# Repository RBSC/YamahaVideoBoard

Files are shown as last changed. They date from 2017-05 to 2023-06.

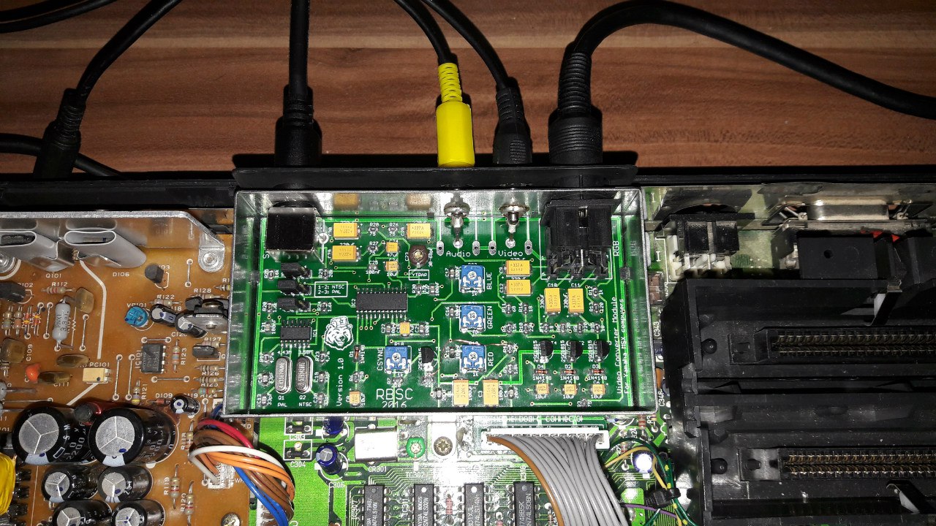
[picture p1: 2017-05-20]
Pics/installed.jpg

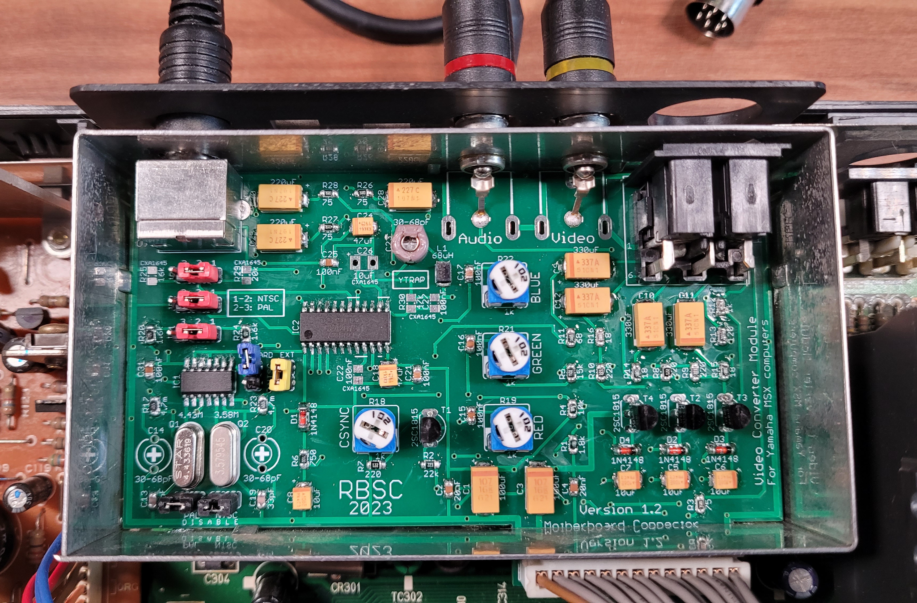
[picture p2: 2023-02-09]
Pics/tantalum_installed.jpg

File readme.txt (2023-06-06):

Improved Video Board for Yamaha MSXs version 1.2
Copyright (c) 2016-2023 RBSC

About
-----

This is the improved video board for Yamaha YIS503II, YIS503III and similar MSX/MSX2 computers to replace the original video
boards or the older versions of the video boards from RBSC. The changes to the v1.2 board comparing to the previous verions are:

- Allows to use either CXA1645 or CXA2075 video encoder chips
- Contains an improved YTRAP filter
- Allows to use through-hole electrolytic capacitors (see note below)
- Allows to switch between on-board and internal MSX's 3.58MHz clock generator for NTSC
- Allows to disable one or both on-board clock generators
- Requires less components if CXA2075 encoder is used
- If using only computer's 3.58Mhz and NTSC, there's no need to assemble both clock generators

It is possible to use some components from the old black-and-white video board from the YIS503IIIR computer to build the v1.2
board. The following components can be re-used:

- 330uF capacitors (4)
- 10uF capacitors (4)
- 2sc1684 transistors (4)
- 100uF capacitors (2)
- DIN8 female socket
- Male 13-pin connector for motherboard's cable

IMPORTANT! When installing 100uF capacitors from the original board, please make sure to install the 16v rated capacitor as C3
and the 10v rated capacitor as C2. Otherwise, the 10v rated capacitor installed as C3 may blow up!

WARNING!
--------

Do not install ONBOARD and EXT jumpers at the same time! When using the EXT jumper, disable both NTSC and PAL clock generators
with their respective jumpers (see below).

The pinout of the RGB connector on the new video board differs from the original pinout! On the new board pin 3 is connected to
+12v supply. When making RGB to SCART cables or when using such cables designed for the Japanese MSX mashines, please make sure
that you connect the +12v to the correct SCART pin - pin 8. Connecting +12v to this pin will switch the TV/monitor to 4:3 mode.

DO NOT connect the cable from Yamaha YIS805 to this video board! The pin order is different on the YIS805 and you will damage
the board if you connect it to YIS805!

It is advised to power down the computer before switching between PAL and NTSC in order to avoid damage to the encoder chip.

Settings
--------

Compared to v1.1 of the videoboard, there are more jumpers. The jumpers labeled as PAL or NTSC DISABLE are used to disable the
on-board PAL or NTSC clock generators and use the internal computer's 3.58MHz clock for NTSC encoding. The installed jumper
disables the clock generator.

The ONBOARD and EXT jumpers are used to select which clock to use for NTSC encoding. When using the EXT jumper, the computer's
internal 3.58MHz clock will be fed to the encoder chip. This will effectively eliminate all color atrefacts in the composite
video output. But this will work only with NTSC mode. The installed jumper enables either on-board or external clock signal.
Never install both jumpers at the same time! Please note that the jumper settings do not affect the RGB output.

There are three 3-pin mode selection jumpers on the video board. These jumpers are used to set the color encoding for the S-Video
and composite video outputs. All 3 jumpers must be set the same way. When the pins 1-2 of the jumpers are shorted, the NTSC
encoding is enabled. Otherwise, when pins 2-3 of the jumpers are shorted, the PAL encoding is enabled. Please note that the
jumper settings do not affect the RGB output.

When setting up the board, it's recommended to measure the voltages on the outputs of 4 potentiometers (variable resistors). The
measurement should be done on the central pin. The correct voltage setting is required to form the stable picture on the
composite video and S-Video outputs.

When using the CXA1645 encoder chip, the recommended voltage for the CSYNC variable resistor is 1.3v, the recommended voltages
for Red, Green and Blue variable resistors are from 1.5v to 2.0v, depending on the desired brightness. The voltages on R, G and
B channels must be the same to avoid color distortion. Each color should be tuned after setting it as background color - for
example when setting the blue color's voltage, use the "color15,4,4" command in Basic to set blue as background color. For
green color use the "color15,2,2" command and for red color use the "color15,6,6" command.

When using the CXA2075 encoder chip, the voltage for CSYNC variable resistor should be set to 1.5v and the voltages for Red,
Green and Blue variable resistors should be set up to 3.0v to reach the desired brightness.

Notes
-----

When using the CXA2075 video encoder, it's not neccessary to install the following elements: C22, C23, C26, C27, R25, R29, R30.
Also, if L1 is not installed, please bridge its solder pads with a wire. However, it's highly recommended to use L1 for better
results.

When planning to use only NTSC encoding with the internal MSX's clock, it may not be necessary to install both oscillators,
both trim capacitors, 74HCT04 chip, C31, C13, C19, R17, R20, R23, as well as optional capacitors on the back side of the board.

Please use the following oscillators: 3.579MHz for NTSC and 4.433MHz for PAL. Using other oscillators may cause undesired side
effects.

It is recommended to use the 74HCT04 chip for the frequency generator circuit. The HC series chips may also work, but the HCT
series is highly recommended.

There may be artefacts on the color transitions in the composite video's output when using the on-board clock generators. These
artefacts can be removed by carefully adjusting the corresponding trim capacitors (C14 or C20) with a small flat screwdriver. 

The sharpness of the composite video output can be adjusted by the C23 trim capacitor that is marked as "YTRAP". Please use a
small flat screwdriver with an isolated handle to trim the capacitors, otherwise interference will occur.

If you are using a jumper pin header instead of the original cable connector, be careful to connect the cable from the MSX's
main board correctly. Incorrect cable connection may damage the video board and your MSX computer!

IMPORTANT!
----------

The RBSC provides all the files and information for free, without any liability (see the disclaimer.txt file). The provided information,
software or hardware must not be used for commercial purposes unless permitted by the RBSC. Producing a small amount of bare boards for
personal projects and selling the rest of the batch is allowed without the permission of RBSC.

When the sources of the tools are used to create alternative projects, please always mention the original source and the copyright!

Contact information
-------------------

The members of RBSC group Tnt23, Wierzbowsky, Pyhesty, Ptero, GreyWolf, SuperMax, VWarlock and DJS3000 can be contacted via the group's
e-mail address:

info@rbsc.su

The group's coordinator could be reached via this e-mail address:

admin@rbsc.su

The group's website can be found here:

https://rbsc.su/
https://rbsc.su/ru

The RBSC's hardware repository can be found here:

https://github.com/rbsc

The RBSC's 3D model repository can be found here:

https://www.thingiverse.com/groups/rbsc/things

-= ! MSX FOREVER ! =-

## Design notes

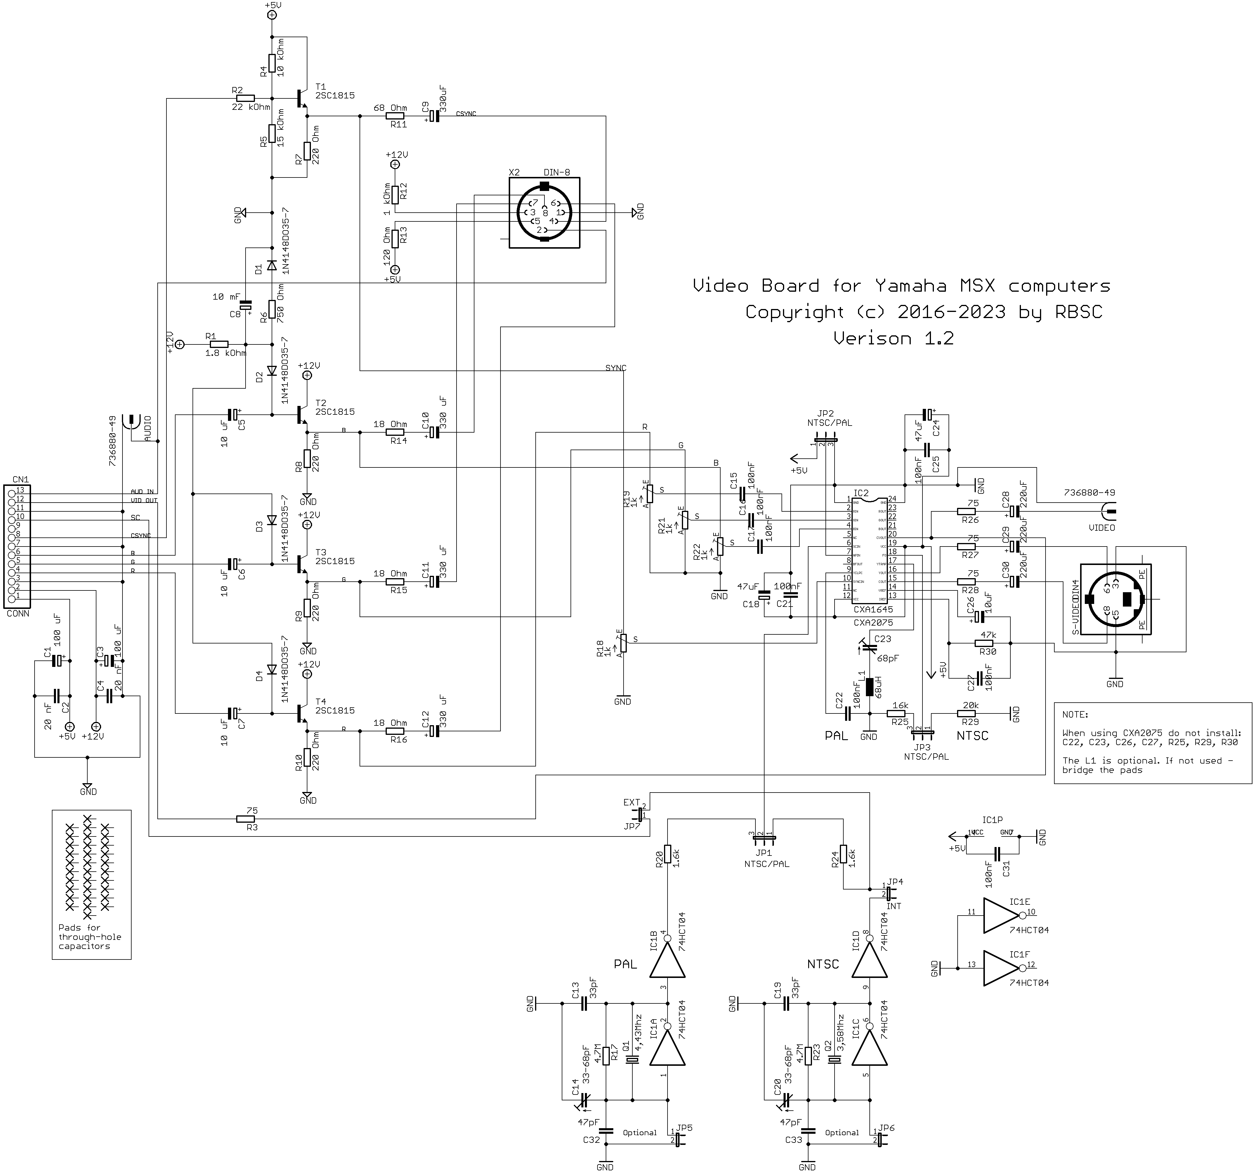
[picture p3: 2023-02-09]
Doc/schematics.png

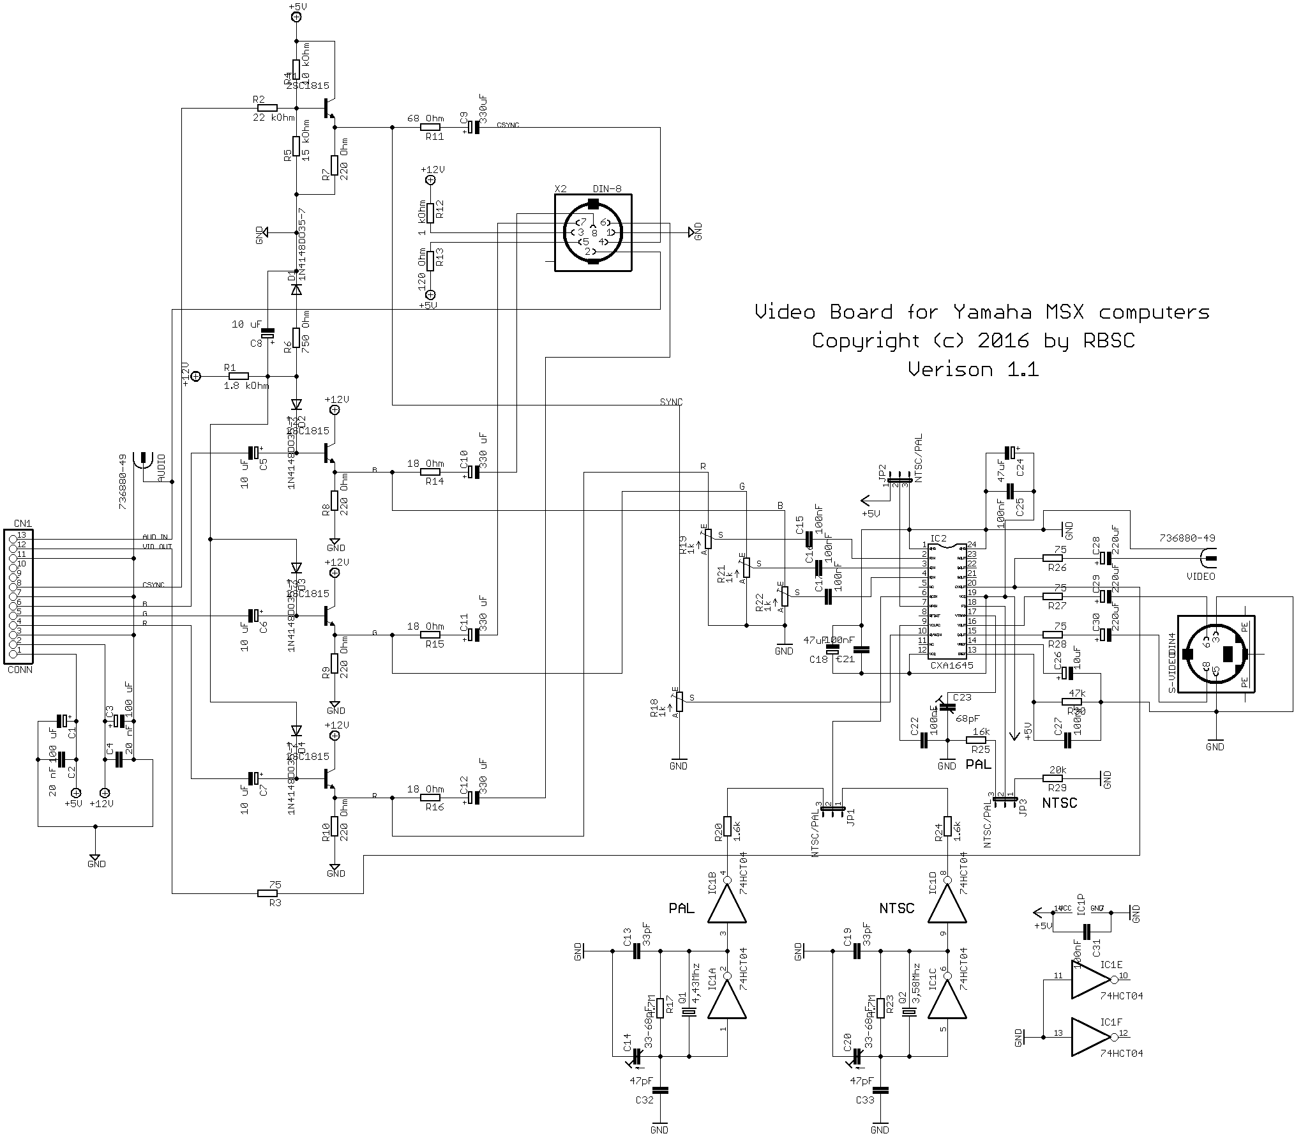
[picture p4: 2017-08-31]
Doc/schematics_v11.png

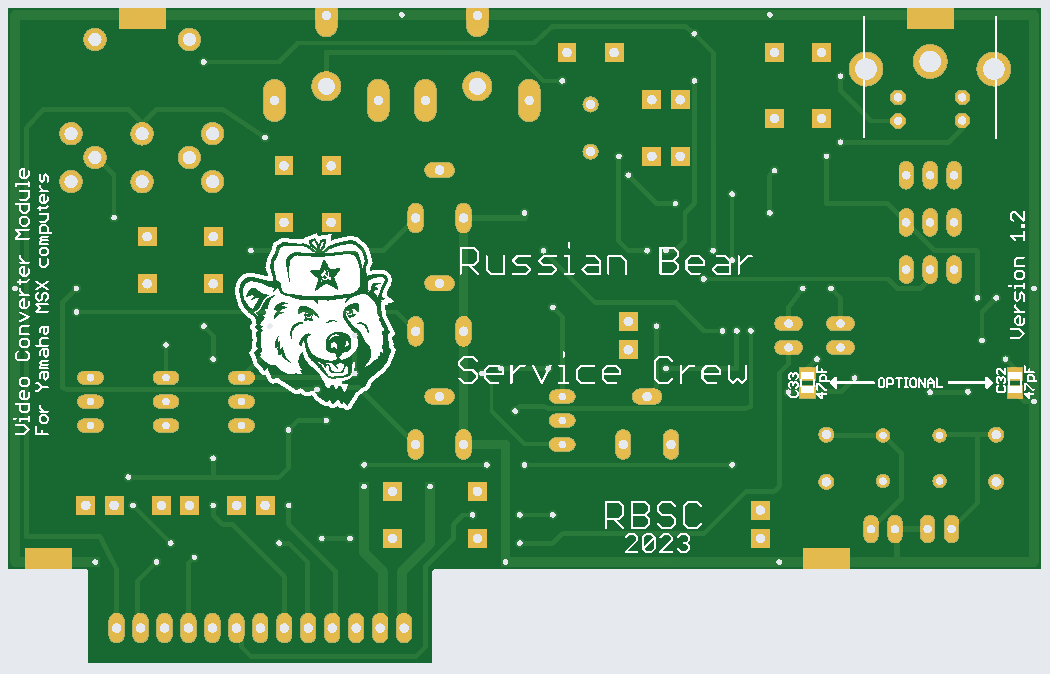
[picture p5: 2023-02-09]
Pics/board_bottom.png

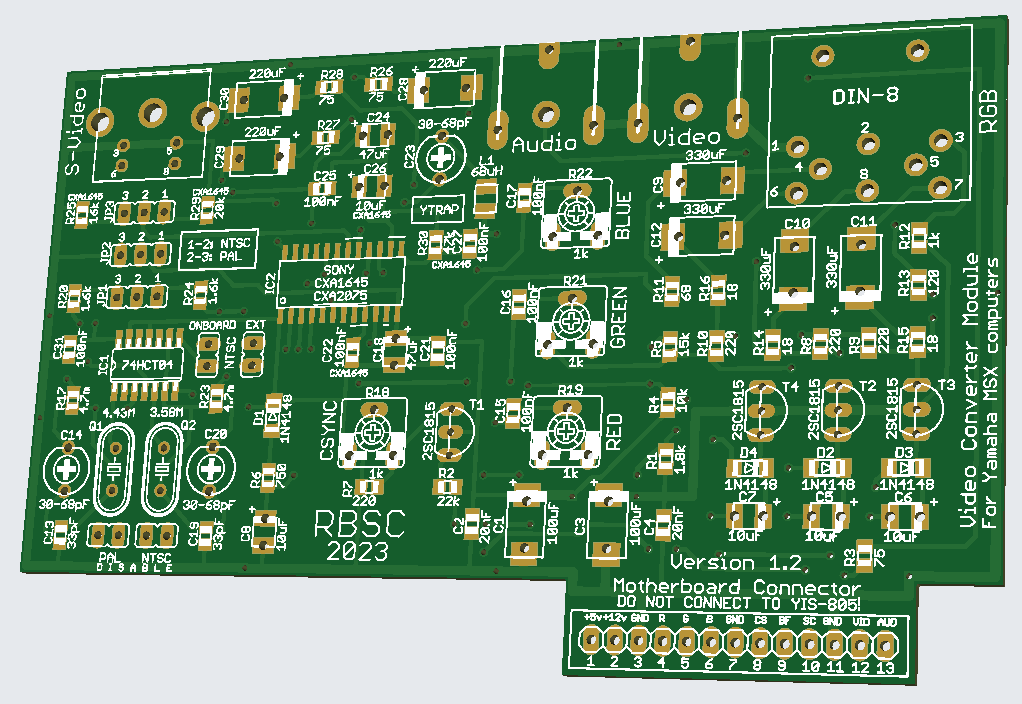
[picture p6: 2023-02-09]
Pics/board_3d.png

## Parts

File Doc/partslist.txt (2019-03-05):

Improved Video Board for Yamaha MSXs version 1.1
Copyright (c) 2016 RBSC

Partlist
--------

Assembly variant: 

Part     Value          Package   Library    Position (mm)         Orientation	Notes

AUDIO    736880-49      736880-49 con-conrad (60 65)               R270		Use Yamaha's own output (RCA)
C1       100 uF         SMC_D     rcl        (60 16)               R270		16v or more!
C2       20 nF          C0805     rcl        (54 16)               R270
C3       100 uF         SMC_D     rcl        (69 16)               R270		16v or more!
C4       20 nF          C0805     rcl        (75 16)               R270
C5       10 uF          SMC_B     rcl        (92 17)               R180		10v or more
C6       10 uF          SMC_B     rcl        (100 17)              R180		10v or more
C7       10 uF          SMC_B     rcl        (84 17)               R180		10v or more
C8       10 uF          SMC_B     rcl        (30 15)               R270		10v or more
C9       330 uF         SMC_D     rcl        (78 53)               R0		10v or more
C10      330 uF         SMC_D     rcl        (88 43)               R90		10v or more
C11      330 uF         SMC_D     rcl        (95 43)               R90		10v or more
C12      330 uF         SMC_D     rcl        (78 47)               R0		10v or more
C13      33pF           C0805     rcl        (5 14.5)              R90
C14      33-68pF        CTRIMTZ03 rcl        (5 22)                R180
C15      100nF          C0805     rcl        (58 28)               R270
C16      100nF          C0805     rcl        (58 40)               R270
C17      100nF          C0805     rcl        (58 52)               R270
C18      47uF           SMC_B     rcl        (44 35)               R270		10v or more
C19      33pF           C0805     rcl        (23 14.5)             R90
C20      33-68pF        CTRIMTZ03 rcl        (23 22)               R180
C21      100nF          C0805     rcl        (49 35)               R270
C22      100nF          C0805     rcl        (39 35)               R270
C23      68pF           CTRIMTZ03 rcl        (48 57)               R180
C24      47uF           SMC_B     rcl        (40 60)               R0		10v or more
C25      100nF          C0805     rcl        (34 54)               R0
C26      10uF           SMC_B     rcl        (40 54)               R0		10v or more
C27      100nF          C0805     rcl        (52 47)               R90
C28      220uF          SMC_D     rcl        (48 65)               R0		10v or more
C29      220uF          SMC_D     rcl        (26 58)               R180		10v or more
C30      220uF          SMC_D     rcl        (26 65)               R180		10v or more
C31      100nF          C0805     rcl        (4 36)                R90
C32      47pF           C0805     rcl        (3 30)                MR90		(optional, back side)
C33      47pF           C0805     rcl        (25 30)               MR90		(optional, back side)
CONN     CN1            1X13      pinhead    (83 4)                R0
D1       1N4148DO35-7   MINIMELF  diode      (30 28)               R270
D2       1N4148DO35-7   MINIMELF  diode      (92 22)               R180
D3       1N4148DO35-7   MINIMELF  diode      (100 22)              R180
D4       1N4148DO35-7   MINIMELF  diode      (84 22)               R180
IC1      74HCT04        SO14      74xx-eu    (14 34)               R0
IC2      CXA1645        SOP24     CXA1645M   (37 43)               R0
JP1      NTSC/PAL       JP2       jumper     (12 42)               R180
JP2      NTSC/PAL       JP2       jumper     (12 47)               R180
JP3      NTSC/PAL       JP2       jumper     (12 52)               R180
Q1       4,43Mhz        HC49/S    crystal    (11 22)               R270		Use 4.433 MHz oscillator
Q2       3,58Mhz        HC49/S    crystal    (17 22)               R270		Use 3.579 MHz oscillator
R1       1.8 kOhm       R0805     resistor   (75 23)               R90
R2       22 kOhm        R0805     resistor   (51 20)               R180
R3       75             R0805     rcl        (96 13)               R270
R4       10 kOhm        R0805     resistor   (75 29)               R270
R5       15 kOhm        R0805     resistor   (75 35)               R90
R6       750 Ohm        R0805     resistor   (30 21)               R90
R7       220 Ohm        R0805     resistor   (42 20)               R0
R8       220 Ohm        R0805     resistor   (91 35)               R270
R9       220 Ohm        R0805     resistor   (96 35)               R270
R10      220 Ohm        R0805     resistor   (80 35)               R90
R11      68 Ohm         R0805     resistor   (75 41)               R270
R12      1 kOhm         R0805     resistor   (101 46)              R90
R13      120 Ohm        R0805     resistor   (101 41)              R270
R14      18 Ohm         R0805     resistor   (86 35)               R270
R15      18 Ohm         R0805     resistor   (101 35)              R270
R16      18 Ohm         R0805     resistor   (80 41)               R270
R17      4.7M           R0805     rcl        (5 30)                R90
R18      1k             CA6V      pot        (42 26)               R0
R19      1k             CA6V      pot        (64 26)               R0
R20      1.6k           R0805     rcl        (4 42)                R90
R21      1k             CA6V      pot        (64 38)               R0
R22      1k             CA6V      pot        (64 50)               R0
R23      4.7M           R0805     rcl        (23 30)               R90
R24      1.6k           R0805     rcl        (20 42)               R90
R25      16k            R0805     rcl        (4 52)                R90
R26      75             R0805     rcl        (40 66)               R180
R27      75             R0805     rcl        (34 60)               R0
R28      75             R0805     rcl        (34 66)               R0
R29      20k            R0805     rcl        (20 52)               R270
R30      47k            R0805     rcl        (48 47)               R270
S-VIDEO  DIN4           M_DIN4    mini_din   (12 64)               R0
T1       2SC1815        TO92-ECB  transistor (51 26)               R270
T2       2SC1815        TO92-ECB  transistor (93 28)               R270
T3       2SC1815        TO92-ECB  transistor (101 28)              R270
T4       2SC1815        TO92-ECB  transistor (85 28)               R270
VIDEO    736880-49      736880-49 con-conrad (76 65)               R270		Use Yamaha's own output (RCA)
X2       DIN-8          DIN8      din8       (96 60)               R180

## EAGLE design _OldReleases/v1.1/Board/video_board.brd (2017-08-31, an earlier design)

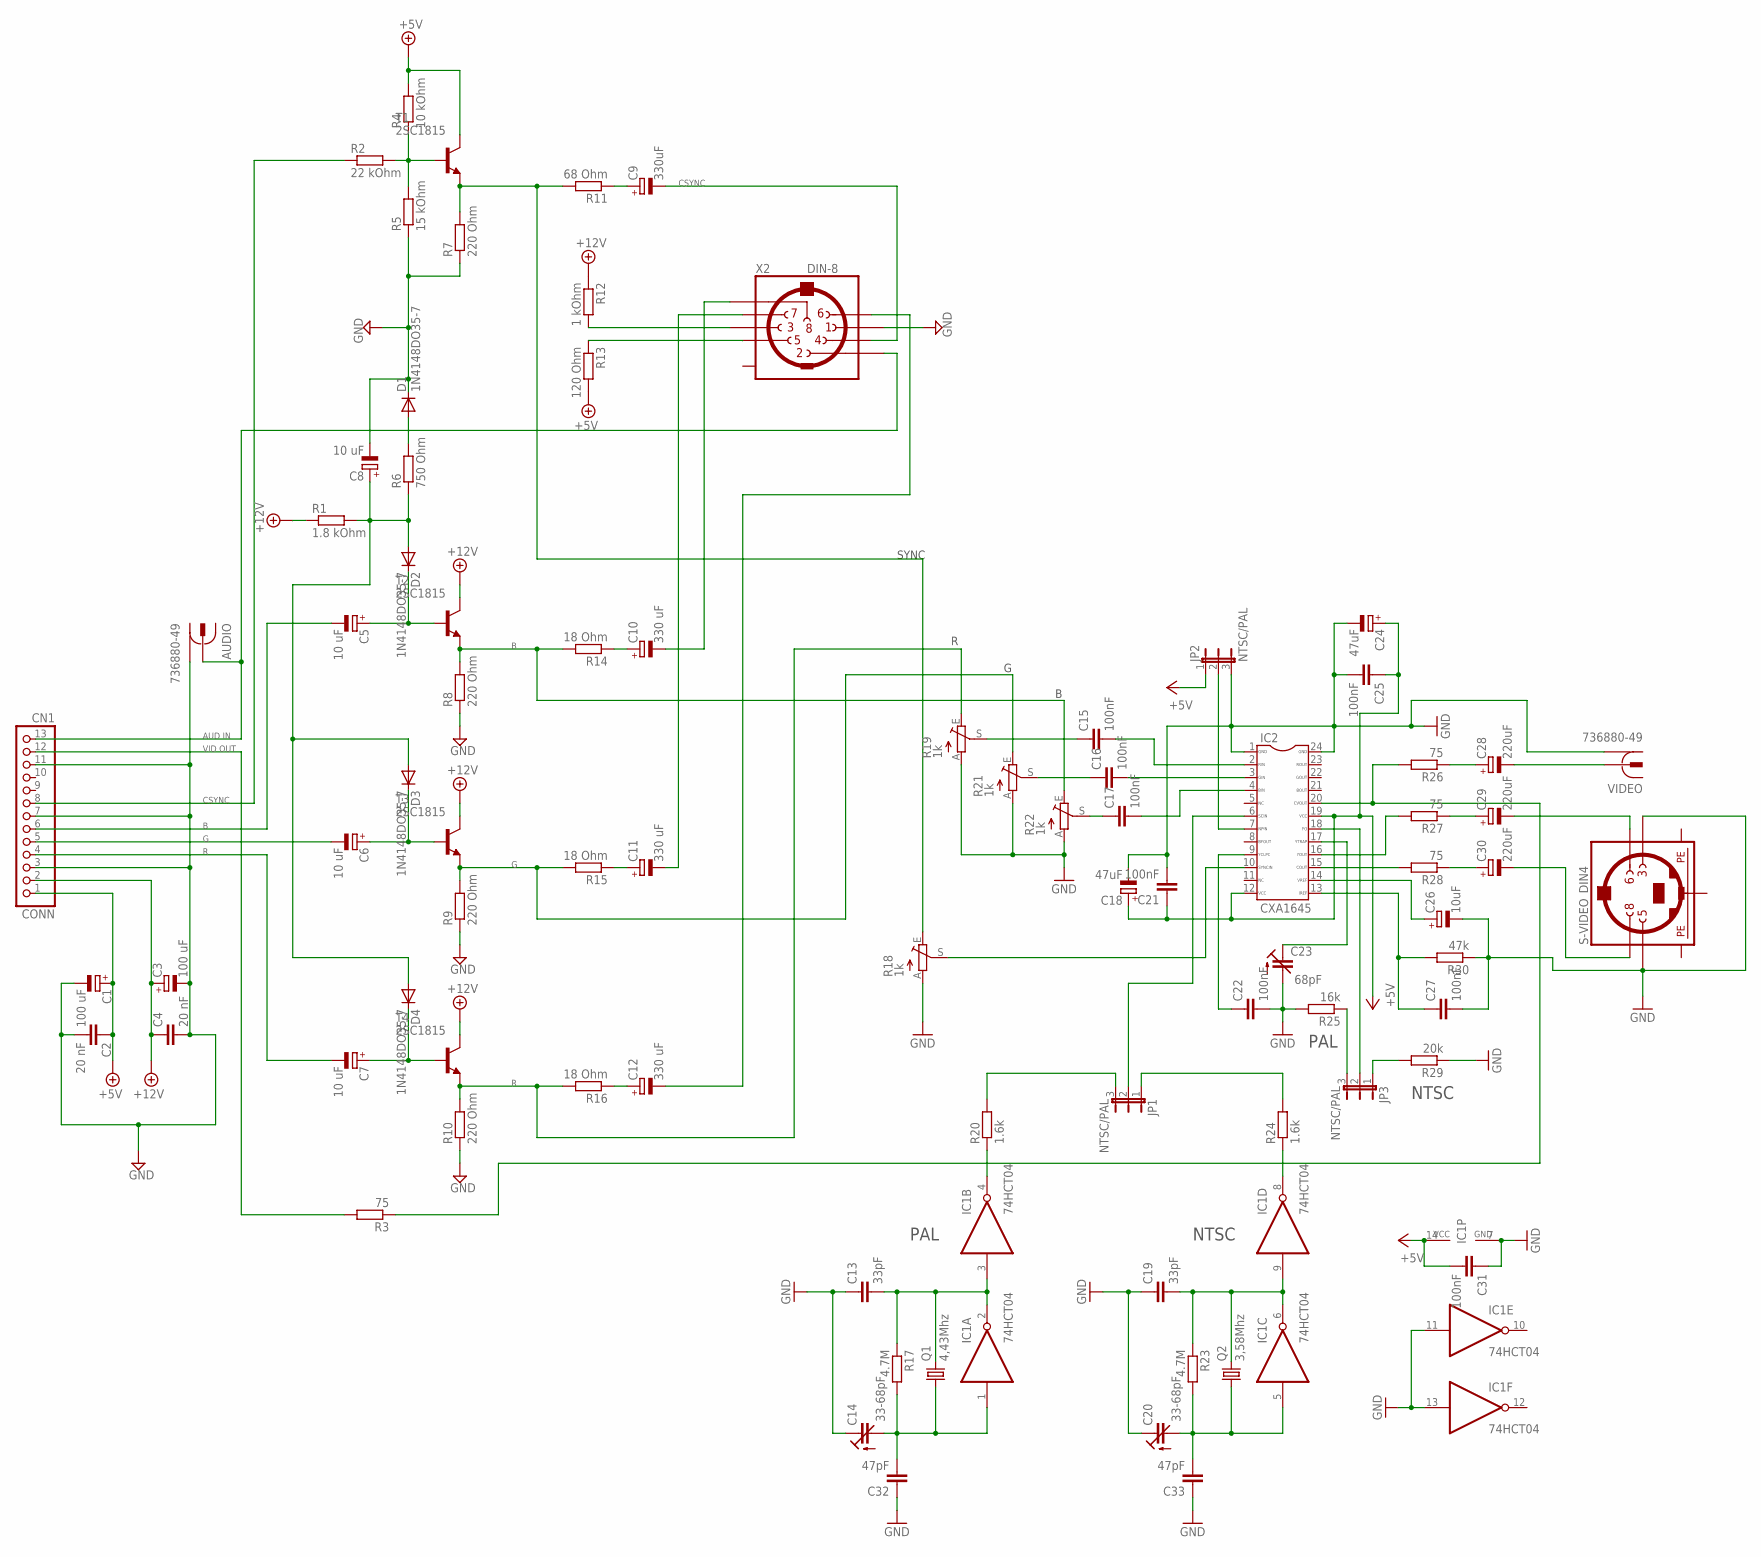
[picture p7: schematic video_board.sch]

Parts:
AUDIO: 736880-49
C1, C3: 100 uF; SMC_D
C2, C4: 20 nF; C0805
C5, C6, C7, C8: 10 uF; SMC_B
C9: 330uF; SMC_D
C10, C11, C12: 330 uF; SMC_D
C13, C19: 33pF; C0805
C14, C20: 33-68pF; CTRIMTZ03
C15, C16, C17, C21, C22, C25, C27, C31: 100nF; C0805
C18, C24: 47uF; SMC_B
C23: 68pF; CTRIMTZ03
C26: 10uF; SMC_B
C28, C29, C30: 220uF; SMC_D
C32, C33: 47pF; C0805
CONN: CN1; 1X13
D1, D2, D3, D4: 1N4148DO35-7; MINIMELF
IC1: 74HCT04; SO14
IC2: CXA1645; SOP24
JP1, JP2, JP3: NTSC/PAL; JP2
Q1: 4,43Mhz; HC49/S; MPN HC49SM-3.6864-30-50-60-16-ATF
Q2: 3,58Mhz; HC49/S; MPN HC49SM-3.6864-30-50-60-16-ATF
R1: 1.8 kOhm; R0805
R2: 22 kOhm; R0805
R3, R26, R27, R28: 75; R0805
R4: 10 kOhm; R0805
R5: 15 kOhm; R0805
R6: 750 Ohm; R0805
R7, R8, R9, R10: 220 Ohm; R0805
R11: 68 Ohm; R0805
R12: 1 kOhm; R0805
R13: 120 Ohm; R0805
R14, R15, R16: 18 Ohm; R0805
R17, R23: 4.7M; R0805
R18, R19, R21, R22: 1k; CA6V
R20, R24: 1.6k; R0805
R25: 16k; R0805
R29: 20k; R0805
R30: 47k; R0805
S-VIDEO: DIN4; M_DIN4
T1, T2, T3, T4: 2SC1815; TO92-ECB
VIDEO: 736880-49
X2: DIN-8; DIN8

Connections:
+5V: C1.+, C2.1, C18.+, C21.1, C24.+, C25.1, C31.2, CONN.1, IC1.14 (VCC), IC2.12, IC2.19, JP2.1, R4.2, R13.2, T1.C
+12V: C3.+, C4.1, CONN.2, R1.1, R12.1, T2.C, T3.C, T4.C
GND: AUDIO.1, AUDIO.1@1 (1), AUDIO.1@2 (1), C1.-, C2.2, C3.-, C4.2, C8.-, C13.1, C14.1 (E), C18.-, C19.1, C20.1 (E), C21.2, C22.2, C23.2 (A), C24.-, C25.2, C26.-, C27.2, C31.1, C32.1, C33.1, CONN.3, CONN.7, CONN.11, D1.C, IC1.7 (GND), IC1.11 (I), IC1.13 (I), IC2.1, IC2.24, JP2.3, R5.1, R7.1, R8.1, R9.1, R10.1, R18.A, R19.A, R21.A, R22.A, R25.2, R29.1, R30.1, S-VIDEO.3, S-VIDEO.5, VIDEO.1, VIDEO.1@1 (1), VIDEO.1@2 (1), X2.1
unnamed: R10.2, R16.2, R19.E, T4.E
unnamed: C20.2 (A), C33.2, IC1.5 (I), Q2.1, R23.2
unnamed: JP1.1, R24.2
unnamed: CONN.8, R2.1
unnamed: R8.2, R14.2, R22.E, T2.E
unnamed: C15.1, R19.S
unnamed: C16.1, R21.S
unnamed: IC1.4 (O), R20.1
unnamed: IC1.8 (O), R24.1
unnamed: C19.2, IC1.6 (O), IC1.9 (I), Q2.2, R23.1
unnamed: JP1.3, R20.2
unnamed: C8.+, D2.A, D3.A, D4.A, R1.2, R6.1
unnamed: JP3.3, R25.1
unnamed: IC2.7, JP2.2
unnamed: JP3.1, R29.2
unnamed: IC2.16, R27.2
unnamed: CONN.12, R3.2
unnamed: C23.1 (E), IC2.17
unnamed: C12.-, X2.6
unnamed: C11.-, X2.7
unnamed: C6.+, D3.C, T3.B
unnamed: C10.-, X2.8
unnamed: D1.A, R6.2
unnamed: C6.-, CONN.5
unnamed: C5.-, CONN.6
unnamed: AUDIO.2, CONN.13, X2.2
unnamed: C12.+, R16.1
unnamed: R12.2, X2.3
unnamed: R9.2, R15.2, R21.E, T3.E
unnamed: R13.1, X2.5
unnamed: C7.+, D4.C, T4.B
unnamed: C7.-, CONN.4
unnamed: C5.+, D2.C, T2.B
unnamed: R2.2, R4.1, R5.2, T1.B
unnamed: R7.2, R11.2, R18.E, T1.E
unnamed: C11.+, R15.1
unnamed: C10.+, R14.1
unnamed: C9.+, R11.1
unnamed: C9.-, X2.4
unnamed: C17.1, R22.S
unnamed: C16.2, IC2.3
unnamed: C15.2, IC2.2
unnamed: C17.2, IC2.4
unnamed: C14.2 (A), C32.2, IC1.1 (I), Q1.1, R17.2
unnamed: C13.2, IC1.2 (O), IC1.3 (I), Q1.2, R17.1
unnamed: IC2.10, R18.S
unnamed: IC2.6, JP1.2
unnamed: IC2.20, R3.1, R26.2
unnamed: C22.1, IC2.9
unnamed: IC2.18, JP3.2
unnamed: IC2.15, R28.2
unnamed: C28.+, R26.1
unnamed: C29.+, R27.1
unnamed: C30.+, R28.1
unnamed: C26.+, IC2.14
unnamed: C27.1, IC2.13, R30.2
unnamed: C28.-, VIDEO.2
unnamed: C29.-, S-VIDEO.6
unnamed: C30.-, S-VIDEO.8
PE1: S-VIDEO.SH1 (PE1)
PE2: S-VIDEO.SH2 (PE2)
PE3: S-VIDEO.SH3 (PE3)

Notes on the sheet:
CSYNC
AUD IN
VID OUT
SYNC
PAL
NTSC

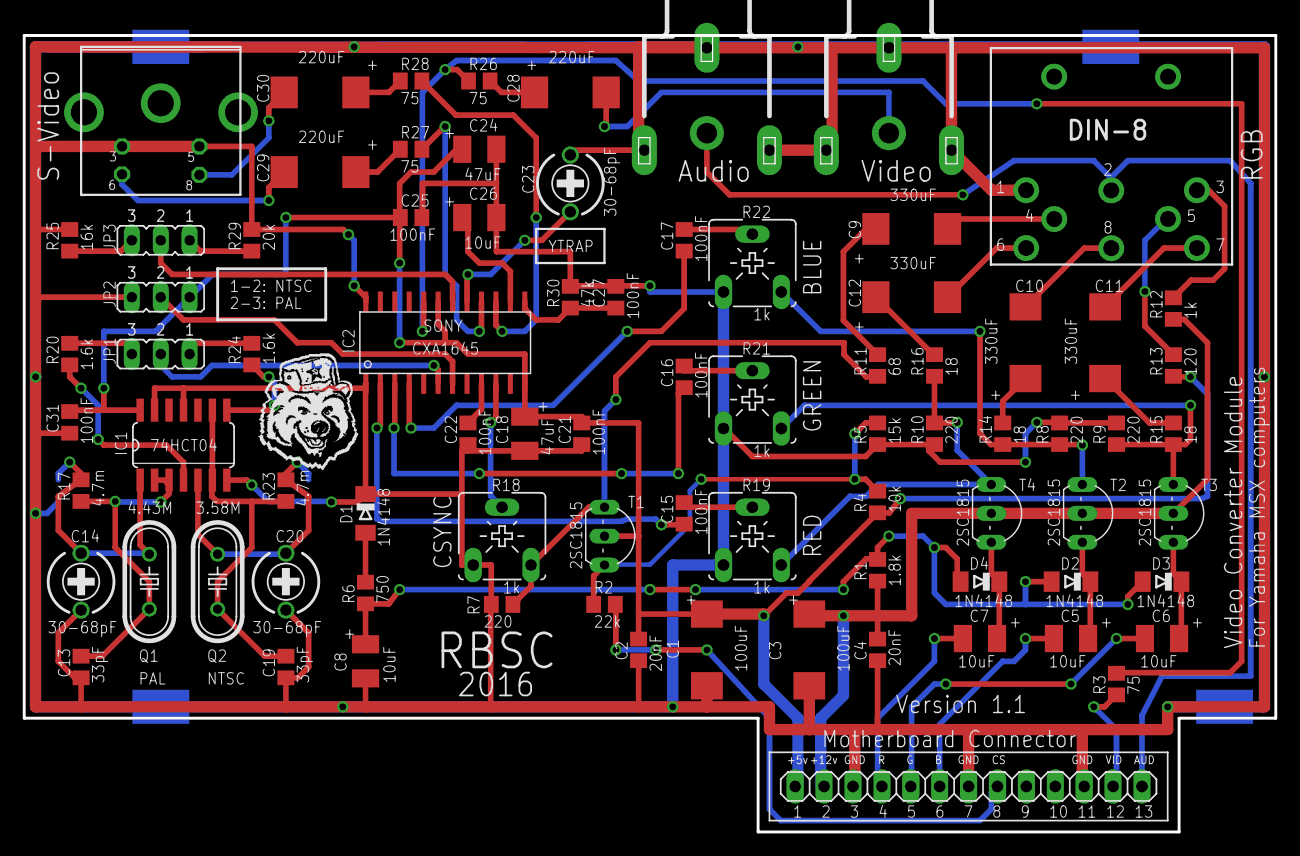
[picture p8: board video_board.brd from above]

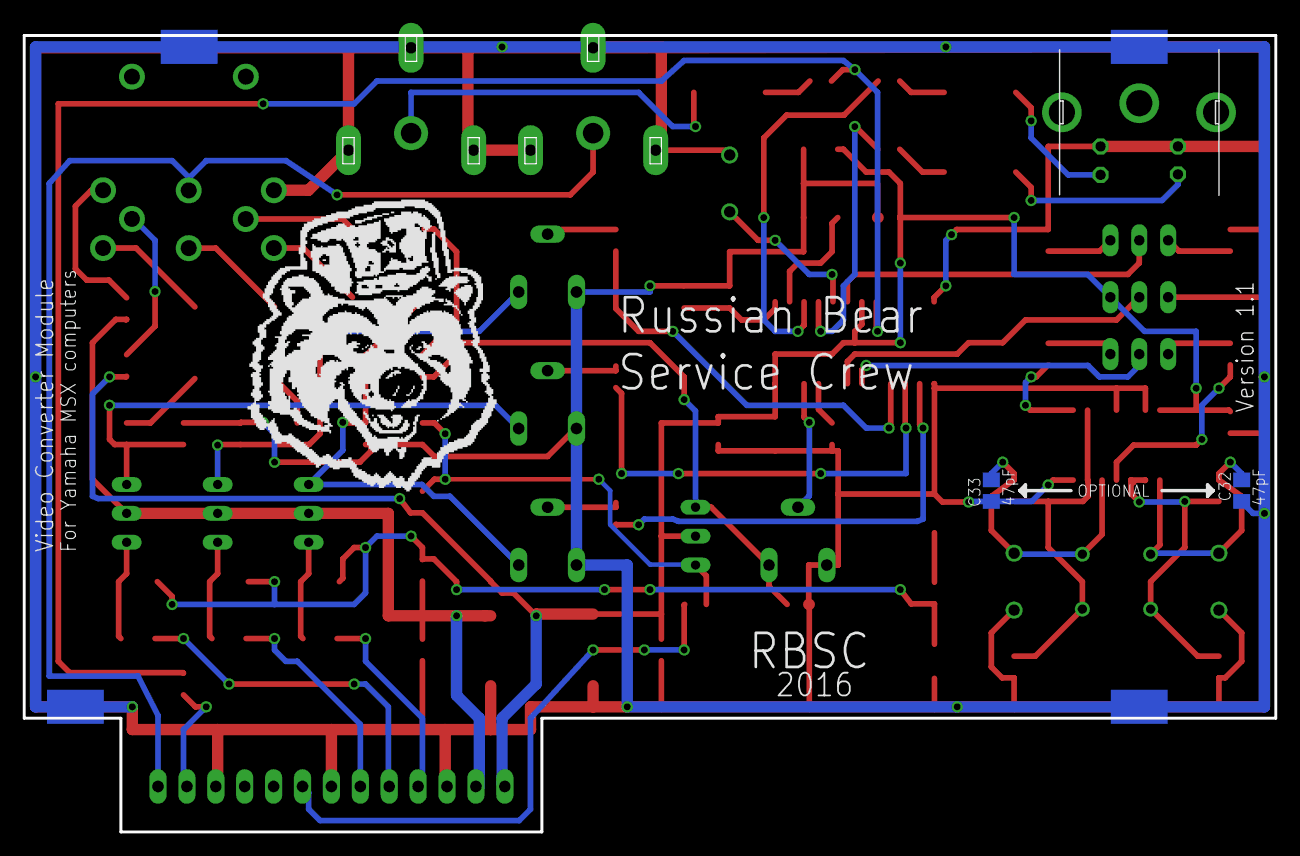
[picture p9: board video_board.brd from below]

Board: 2 copper layers, 110.0 x 70.0 mm, 83 parts (2 on the bottom side), 62 nets.

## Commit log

2016-07-19 Board version 1.1
    Yamaha video board version 1.1
    [video_board.brd, video_board.sch]
2017-05-20 Added readme files
    [video_board.brd, video_board.sch]
2017-08-31 Latest fixes for schematics and partslist
    Fixed incorrect C8 value in partslist and schematics
    [video_board.brd, video_board.sch]
2023-02-09 Release 09.02.2023
    Video board v1.2 release
    [video_board.brd, video_board.sch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]
2023-02-10 Release 09.02.2023
    Updated the assembled board's picture

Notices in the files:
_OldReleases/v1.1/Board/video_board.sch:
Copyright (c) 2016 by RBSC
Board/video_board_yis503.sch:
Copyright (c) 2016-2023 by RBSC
